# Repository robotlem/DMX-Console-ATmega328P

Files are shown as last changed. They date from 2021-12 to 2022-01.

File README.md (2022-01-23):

# DMX-Console-ATmega328P

A cheap and basic DMX console based on an ATmega328P

## About the Project

This DMX console is build for easy tasks like controlling a few spots, running a chaser for a light strip in the background or just testing DMX controlled lamps.
It is easy to use and build.

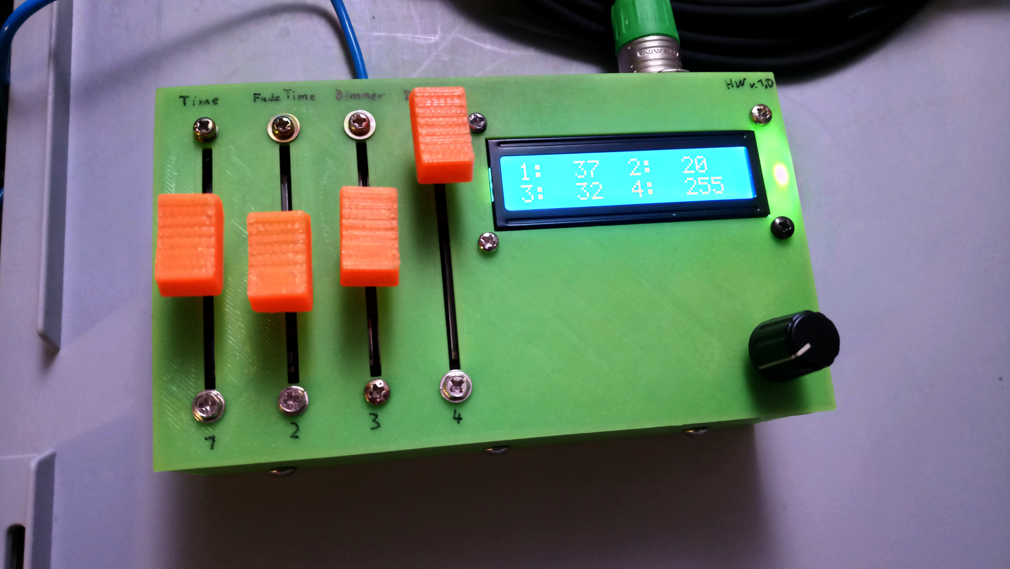
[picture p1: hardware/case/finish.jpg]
finish DMX-Controller


### Features

* Manual control of 72 DMX channels
* 3 Chaser banks which each contains 20 scenes, that stores the first 8 DMX channels
* Alltogether 60 Scenes store- and recallable
* Chaser parameter with faders settable (scenetime, fadetime, dimmer, direction)
* Startmode settable (manual, scene recall, chaser)
* relativly cheap (under 30€)

### Libaries used

* Arduino
* EEPROM
* marcoschwartz/LiquidCrystal_I2C@^1.1.4
* mathertel/RotaryEncoder@^1.5.2
* paulstoffregen/DmxSimple@^3.1 (modified, details in software folder)

### License

This project stands under the GNU GPLv3 License - see the LICENSE.md file for details.

## How2 Build

The circuit and BOM is in the hardware folder.
Build the "mainboard" on a perfboard and connect the faders, the LCD, ... with it.
You can also add a voltage regulator to use it with higher voltage.

To flash the software, connect the console (through a programmer) to your computer (if you are using a new ATmega328P you should burn a fitting bootloader first to set the fuses right).
Upload the prepare program (which updates the EEPROM to right start values).
Upload the main program.

Now you can build the components in a fitting case (you find an example in the hardware folder).

## Bugs

There could be some bugs left...
  - the fade time on the LCD is wrong

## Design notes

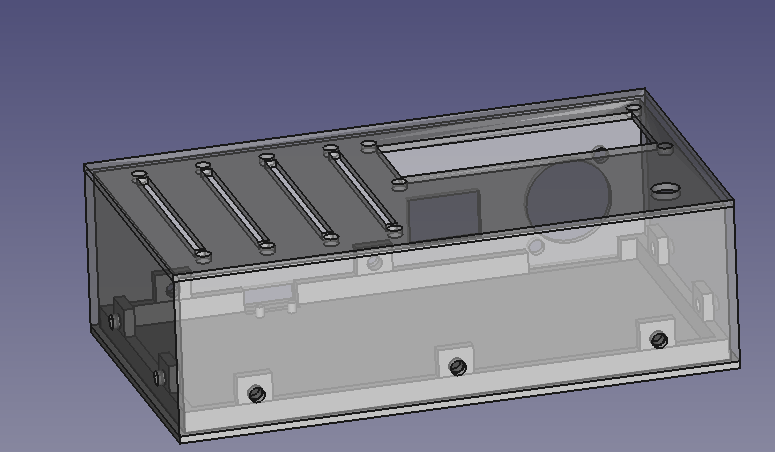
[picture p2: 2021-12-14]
hardware/case/Screenshot_20211214_175523.png

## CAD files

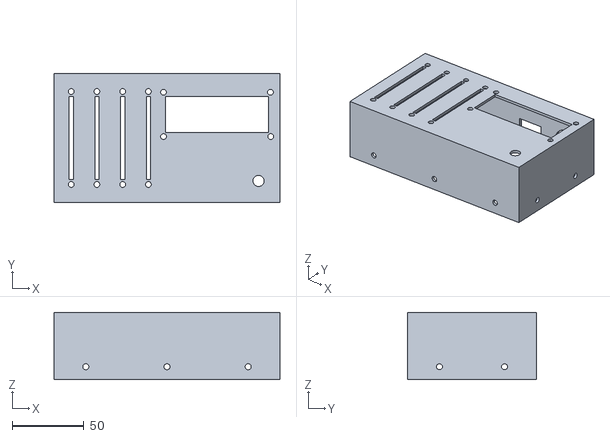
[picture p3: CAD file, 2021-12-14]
hardware/case/Gehäuse V1-OberteilPocket009.stl
158.0 x 90.0 x 47.0

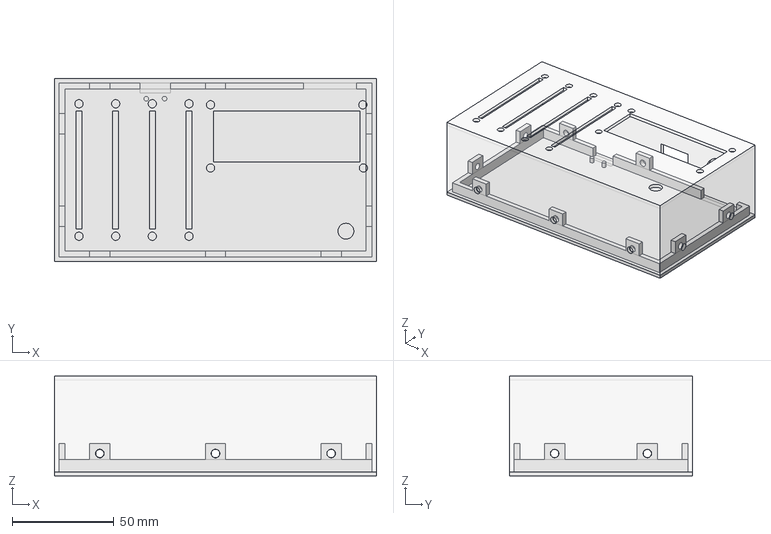
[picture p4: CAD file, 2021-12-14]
hardware/case/Gehäuse V1.FCStd
158.0 x 90.0 x 49.0 mm
Oberteil
Unterteil

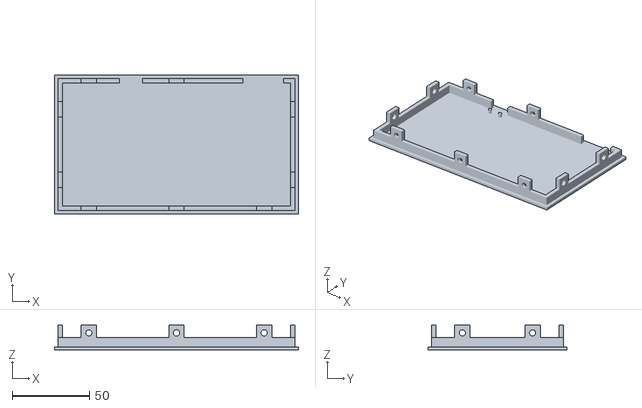
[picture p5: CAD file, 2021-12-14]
hardware/case/Gehäuse V1-UnterteilPad010.stl
158.0 x 90.0 x 16.0

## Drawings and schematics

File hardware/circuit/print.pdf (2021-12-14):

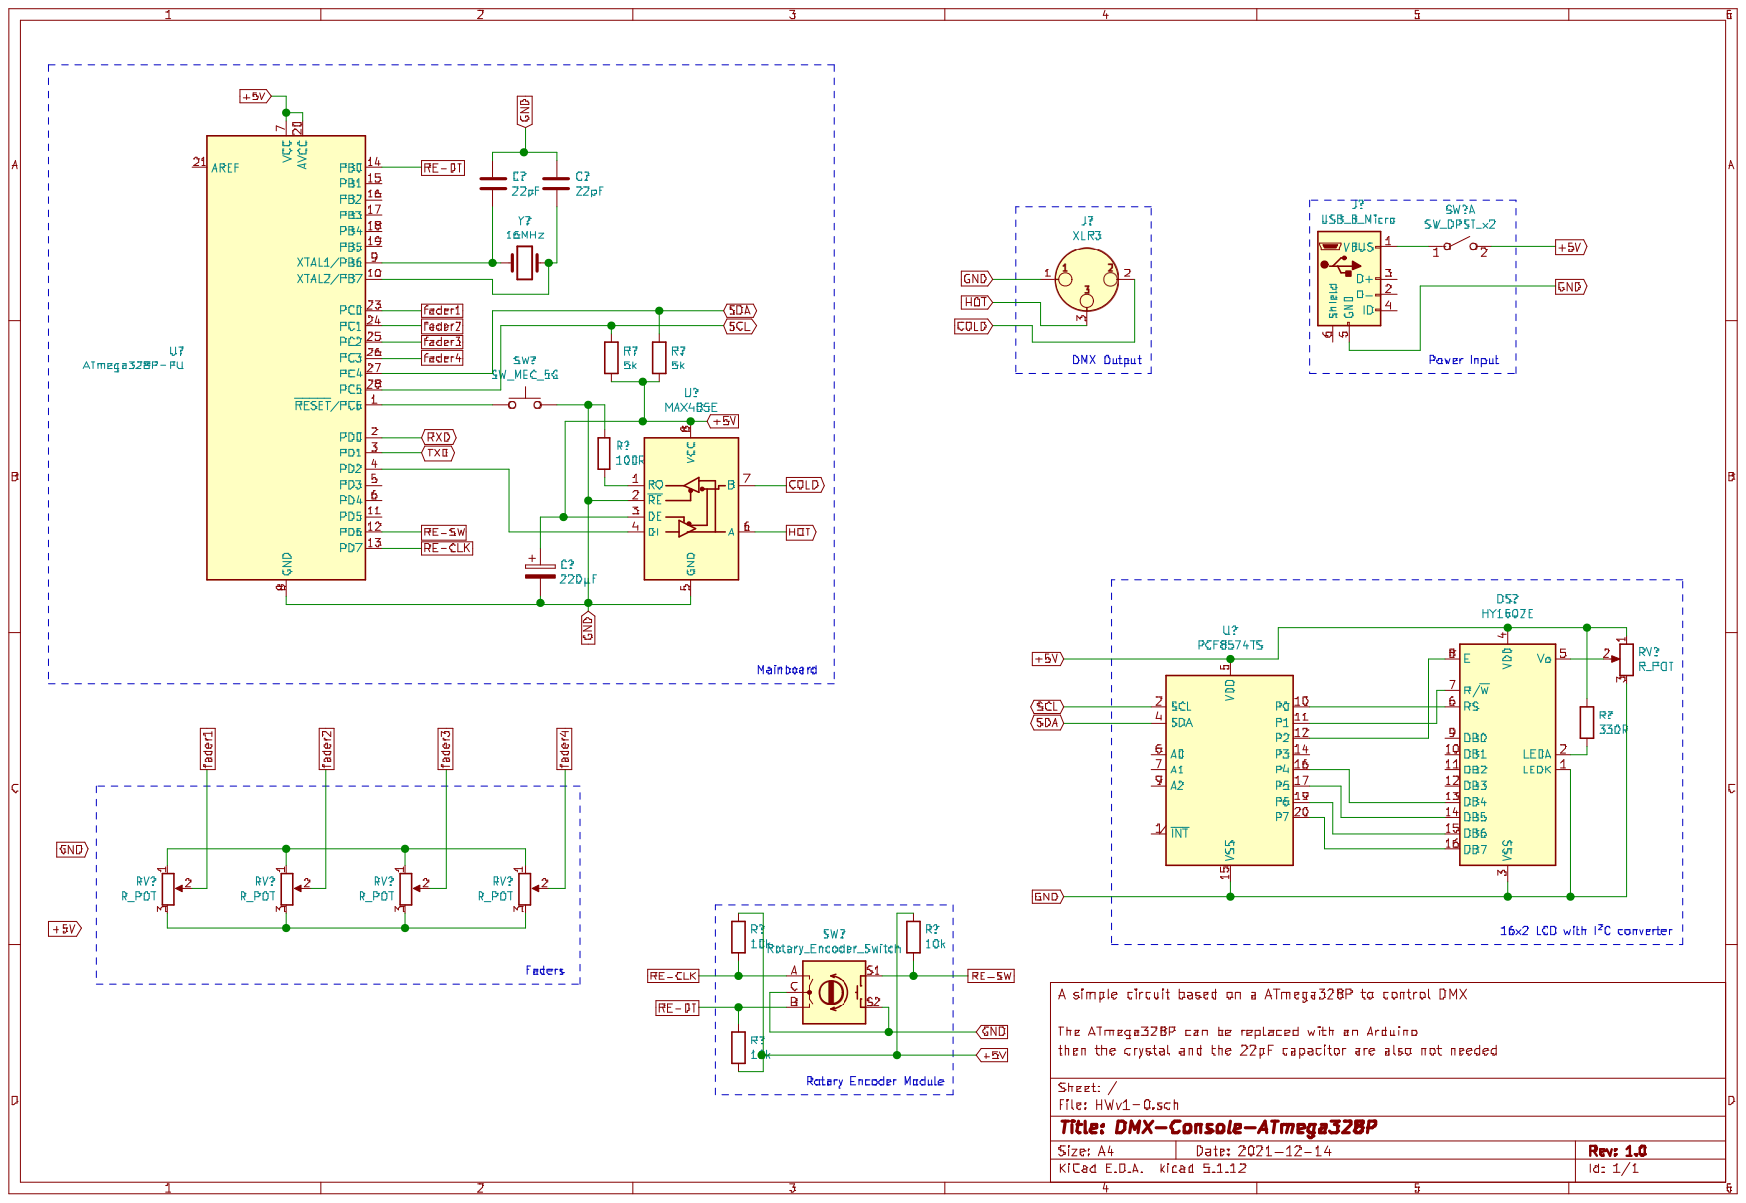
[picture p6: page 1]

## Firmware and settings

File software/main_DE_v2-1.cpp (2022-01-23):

/*
    DMX Controller v2.1
    Copyright (C) 2022 S.Pauthner

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
    You should have received a copy of the GNU General Public License
    along with this program.  If not, see <https://www.gnu.org/licenses/>.
*/

#include <Arduino.h>
#include <LiquidCrystal_I2C.h>
#include <RotaryEncoder.h>
#include <DmxSimple.h>
#include <EEPROM.h>

/* ---  DMX-Controller V2.1 ---
  Programmcode zur Steuerung von DMX Geräten
  für Hardware Version: 1.0
  Software Version:     2.1 beta
  Autor:                S. Pauthner
  Änderungsdatum:       23.01.2022

  Bibliotheken:         LiquidCrystal_I2C, RotaryEncoder, DmxSimple (! Enthält eigene Modifizierungen), EEPROM, Arduino
  Lizenz:               GNU GPLv3

  Features:           - manuelle Steuerung von 72 DMX Kanälen
                      - 3 Chaser mit 20 Scenen der ersten 8 Kanäle
                      - Anpasung der Chaserparameter mit Fadern
                      - einstellbarer Startmodus
                      - insgesamt 60 speicher und abrufbare Scenen á 8 Kanäle in 3 Chasern

  Bugfixes:
                      - FadeTime Anzeige korrigiert
                      - Chaserstart optimiert
                      - LCD update Zeit optimiert

  Default-verkabelung:
    PC6/Reset   --> Taster zu GND
    PD0/RXD     --> Serial Interface
    PD1/TXD     --> Serial Interface
    PD2/D2      --> MAX 485 CPA
    PD3/D3      --> N.C.
    PD4/D4      --> N.C.
    PB6/XTAL1   --> Oszillator 16MHz
    PB7/XTAL2   --> Oszillator 16MHz
    PD5/D5      --> N.C.
    PD6/D6      --> Drehencoder SW
    PD7/D7      --> Drehencoder CLK
    PB0/D8      --> Drehencoder DT

    PB1/D9      --> N.C.
    PB2/D10     --> N.C.
    PB3/D11     --> N.C.
    PB4/D12     --> N.C.
    PB5/D13     --> LED
    PC0/A0      --> Fader 1
    PC1/A1      --> Fader 2
    PC2/A2      --> Fader 3
    PC3/A3      --> Fader 4
    PC4/SCL     --> I²C Display SDA
    PC5/SDA     --> I²C Display SCL
*/

#define PIN_IN1 7   // Drehencoder CLK
#define PIN_IN2 8   // Drehencoder DT
#define PIN_BTN 6   // Drehencoder SW

#define Fader1  0   // Faderbelegung #1
#define Fader2  1   // Faderbelegung #2
#define Fader3  2   // Faderbelegung #3
#define Fader4  3   // Faderbelegung #4
static uint8_t faderInput[4] = {Fader1, Fader2, Fader3, Fader4};

LiquidCrystal_I2C lcd(0x27,16,2);                                               // Objekt lcd erzeugen (I²C Adresse, Spalten, Zeilen)
RotaryEncoder encoder(PIN_IN1, PIN_IN2, RotaryEncoder::LatchMode::TWO03);       // Objekt encoder erzeugen

/* DMX Output */
// DMX Output abrufen mit   DmxSimple.getValue(Channel);    --> Bibliotheksveränderung siehe Anhang "/doc/Recources/README"

/* Chaser Parameter */
unsigned short sceneSpeed = 0;    // die Zeit pro Scene in 100 ms
unsigned short fadeTime = 0;      // die Fadezeit bis zum letztendlichen Wert in 100 ms
unsigned short masterDimmer = 0;  // der Masterdimmer bei Chaseraktivitäten in Prozent (Multiplikator)
unsigned short richtung = 0;      // die Richtung, in der Scenen im Chaser abgerufen werden (Aufsteigend, Absteigend, Hin und Her, Zufall)
static double aktScene[8];        // die aktuelle Chaserscene
static double altScene[8];        // die vorherige Chaserscene
unsigned long timeScene = millis(); // Zeitvariable zur Scenenverwaltung
unsigned long timeFade = millis();// Zeitvariable zur Fadesteuerung
bool nurNull = false;             // Variable zur Überprüfung der Scenenwerte
bool scenedir = true;             // Variable für Hin Her
short fadePosition = 0;           // Variable zum Faden im Chaser (in 255 Schritten)
short lastChaserNr = 0;           // Variable, die die Letzte Scenennummer trägt --> hin her funktion

/* Programmablauf/-steuerung */
static unsigned short lcdUpdateTime = 200; // Anzahl der Millisekunden, bis das LCD geupdatet wird
static uint8_t status[4];         // aktuelle Aufgabe
static uint8_t statusebene = 0;   // Statusebene: 0 = Menu, 1 = Modusauswahl, 2 = Chaserauswahl, 3 = Scenenauswahl
static bool action = false;       // Select Button
static bool printRefresh = true;  // Variable, um das Lcd neu zu Zeichnen
static unsigned long time;        // Variable, die mit millis() gleichgesetzt wird, um ein zu häufiges Updaten des LCDs zu verhindern
static short fader[4];          // Fader Array --> ADC Wert durch 4
static bool faderChange[4] = {true, true, true, true};   // Variable, die bei Änderung der Fader auf true gesetzt wird


// Funktion, um den Drehencoder abzufragen
void trackRE(uint8_t position, uint8_t untergrenze, uint8_t obergrenze, uint8_t modifikator){
  /*
    byte position     : Welcher Index des Arrays/Pointers status/statusPointer modifiziert werden soll
    byte untergrenze  : Wo die Untergrenze der möglichen Werte liegt (Werte zwischen 0 und 255)
    byte obergrenze   : Wo die obergrenze der möglichen Werte liegt (Werte zwischen 0 und 255)
    byte modifikator  : Um wie viel der Wert erhöht bzw. verringert werden soll
  */
  static int pos = 0;
  encoder.tick();
  int newPos = encoder.getPosition();
  if (pos != newPos) {         // RE Aktionen
    // RE nach Links  -  Verringern
    if (pos > newPos+1){       // newPos + 1 um eine grobere erfassung zu bekommen
      if (status[position] <= untergrenze){
        status[position] = obergrenze;
      }
      else{
        status[position] = status[position] - modifikator;
      }
      printRefresh = true;
      pos = newPos;
    }
    // RE nach Rechts  -  Erhöhen
    else if (pos < newPos-1){  // newPos - 1 um eine grobere erfassung zu bekommen
      if (status[position] >= obergrenze){
        status[position] = untergrenze;
      }
      else{
        status[position] = status[position] + modifikator;
      }
      printRefresh = true;
      pos = newPos;
    }

  }
}

// Funktion um einen losgelassenen Selectbutton in eine Variable zu speichern
void buttonPress(){
  /*
    Push RE auslesen
    bei loslassen wird *actionPointer auf true gesetzt
      --> manuelles resetten

    faderChange auf True setzen um werte neu zu laden
  */
  static bool btnPres = false; // Variable zum auslesen des Selectbuttons
  if (digitalRead(PIN_BTN) == false){
    btnPres = true;
  }
  if (digitalRead(PIN_BTN) == true && btnPres == true){
    btnPres = false;
    action = true;
    printRefresh = true;
    for (uint8_t i = 0; i < 4; i++) {
      faderChange[i] = true;
    }
  }

}

// setup Funktion
void setup(){
  lcd.init();                      // LCD initialisieren
  lcd.backlight();
  lcd.begin(16,2);
  lcd.setCursor(1,0);
  lcd.print("DMX-Controller");
  lcd.setCursor(6,1);
  lcd.print("v2.1");

  pinMode(PIN_BTN, INPUT);        // Select Button als Input konfigurieren

  DmxSimple.maxChannel(72);       // DMX universum auf 72 limitieren
  DmxSimple.usePin(2);            // DMX Output Pin: 2
  for (uint8_t i = 1; i <= 72; i++) {
    DmxSimple.write(i, 0);
  }

  for (uint8_t i = 0; i < 4; i++) {    // Anfangsmodus laden
    status[i] = EEPROM.read(600 + i);
  }
  statusebene = EEPROM.read(610);     // Anfangsebene laden

  if (status[0] == 3 || status[0] == 4) {               // Wenn Scene oder Chaser als start, einmal die Szenenaktivität ausführen
    action = true;
  }
  if (status[0] == 4){                                  // bei Chaserstart Scene 1 laden
    for (uint8_t i = 0; i < 8; i++) {
      aktScene[i] = EEPROM.read((status[1]*200 + status[2]*8 + i));
      if (aktScene[i] != 0) {
        nurNull = false;
      }
    }
  }



  delay(700);

}

// loop Funktion

void loop(){

  for (uint8_t i = 0; i < 4; i++) {   // Fader updaten

    if (analogRead(faderInput[i])/4 != fader[i]) {
      fader[i] = analogRead(faderInput[i])/4;
      faderChange[i] = true;
    }

  }

  switch (statusebene) {        // Aktivität nach Statusebene
    case 0: // Menuebene
      trackRE(0, 0, 5, 1);      // Rotary Encoder aktualisieren
      break;
    case 1: // Modusebene/Chaserauswahl
      if (status[0] >= 1 && status[0] <= 4){  // Scene hinzufügen, löschen, abrufen; Chaser Abrufen
        trackRE(1, 0, 3, 1);
      }
      else if (status[0] == 0) {  // Manuell
        trackRE(3, 0, 68, 4);
        for (uint8_t i = 0; i < 4; i++) {
          if (faderChange[i] == true) {
            DmxSimple.write(status[3] + 1 + i, fader[i]);
            faderChange[i] = false;
            printRefresh = true;
          }
        }
      }
      else{ // Einstellungen
          trackRE(1, 0, 3, 1);
      }
      break;

    case 2:
      if (status[0] == 5){  // Einstellungen Chaserauswahl
        trackRE(2, 0, 3, 1);
      }
      else if (status[0] == 4){ // Chaserausführung
        trackRE(2, 0, 19, 1);               // Scrollfunktion durch die Scenen

        for (uint8_t i = 0; i < 4; i++) {   // Manipulationsvariablen anpassen
          if (faderChange[i] == true) {
            switch (i) {
              case 0: // sceneSpeed
                sceneSpeed = (fader[i]*100)/85;
                break;
              case 1: // fadeTime
                fadeTime = (fader[i]*100)/255;
                break;
              case 2: // Dimmer
                masterDimmer = (fader[i]*100)/255;
                for (short i = 0; i < 8; i++) {
                  DmxSimple.write(i + 1 , ((altScene[i] + (((aktScene[i] - altScene[i])/255)*fadePosition))*masterDimmer) / 100 );
                }
                break;
              case 3: // Richtung
                if (fader[i] <= 4){
                  richtung = 0;   // Aufsteigend
                }
                else if (fader[i] <= 38){
                  richtung = 1;   // Absteigend
                }
                else if (fader[i] <= 175){
                  richtung = 2;   // Hin und Her
                }
                else{
                  richtung = 3;   // Zufällig
                }
            }
            faderChange[i] = false;
            printRefresh = true;
          }
        }

        if (millis() - timeScene >= sceneSpeed * 100) { // Eine Scene weiter/ ein Step
          lastChaserNr = status[2];
          for (uint8_t i = 0; i < 8; i++) { // aktuelle Scene in alteScene Speichern
            altScene[i] = aktScene[i];
          }
          nurNull = true;
          int n = 0;
          while(nurNull == true && n < 40){           // aktuelle Scene aus EEPROM lesen und auf NUR NULL prüfen
            n++;
            switch (richtung) {     // Neue Scenennummer erstellen
              case 0: // aufsteigend
                status[2] = status[2] + 1;
                if (status[2] >= 20){
                  status[2] = 0;
                }
                break;
              case 1: // Absteigend
                if (status[2] <= 0) {
                  status[2] = 19;
                }
                else{
                status[2] = status[2] - 1;
                }
                break;
              case 2: // Hin und Her
                if (scenedir == true){    // Aufsteigender Part
                  status[2] = status[2] + 1;
                  if (status[2] >= 19) {
                    scenedir = false;
                  }
                  if (status[2] == lastChaserNr && status[2] <=18) {
                    status[2] = status[2] + 1;
                  }
                }
                else{                     // Sinkender Part
                  status[2] = status[2] - 1;
                  if (status[2] <= 0){
                    scenedir = true;
                  }
                  if (status[2] == lastChaserNr && status[2] >= 1) {
                    status[2] = status[2] - 1;
                  }
                }
                break;
              case 3: // Zufall
                status[2] = random(0, 19);
                break;
              }
              for (uint8_t i = 0; i < 8; i++) {
                aktScene[i] = EEPROM.read((status[1]*200 + status[2]*8 + i));
                if (aktScene[i] != 0) {
                  nurNull = false;
                }
              }
              fadePosition = 0;

          }
          n = 0;
          timeScene = millis();
          printRefresh = true;
        }

        if ((millis() - timeFade >= fadeTime && fadePosition < 256) && fadeTime > 0){ // Faden ermöglichen
          for (short i = 0; i < 8; i++) {
            DmxSimple.write(i + 1 , ((altScene[i] + (((aktScene[i] - altScene[i])/255)*fadePosition))*masterDimmer) / 100 );
          }
          fadePosition = fadePosition + 1;
          timeFade = millis();
        }
        else if (fadeTime <=0 ) {
          for (short i = 0; i < 8; i++) {
            DmxSimple.write(i + 1 , ((aktScene[i])*masterDimmer) / 100 );
          }
          fadePosition = 256;
        }


      }
      else{
        trackRE(2, 0, 20, 1);
      }
      break;
    case 3:
      trackRE(3, 0, 20, 1);
      break;
  }

  buttonPress();            // Select Button aktualisieren

  if (action == true){      // Aktion beim drücken des Select Buttons

    // Zurück (Szene hinzufügen, löschen, abrufen; Chaser Abrufen)
    if ( ((status[1] == 3 && statusebene == 1) || (status[2] == 20 && statusebene == 2)) && (status[0] >= 1 && status[0] <= 4) ){
      if (statusebene <= 0){
        statusebene = 0;
      }
      else{
        statusebene = statusebene - 1;
      }
    }
    // auswählen (Szene hinzufügen, löschen, abrufen; Chaser Abrufen)
    else if (status[0] >= 1 && status[0] <= 4) {
      // Chaserabruf Zurück
      if (status[0] == 4 && statusebene >= 2){
        statusebene = statusebene - 2;
      }

      if (statusebene >= 2){  // Aktionsebene
        switch (status [0]){
          case 1: // Scene hinzufügen
            for (uint8_t i = 0; i < 8; i++) {
              EEPROM.update((status[1]*200) + status[2]*8 + i, DmxSimple.getValue(i + 1));  // Erste 8 DMX Werte in EEPROM speichern
            }
            status[0] = 0;  // Manuell
            statusebene = 0;// Manuell auswahl auf false --> wird im Abschnitt unten umgetriggerd
            break;
          case 2: // Scene löschen
            for (uint8_t i = 0; i < 8; i++) {
              EEPROM.update((status[1]*200) + status[2]*8 + i, 0);  // Erste 8 DMX Werte in EEPROM auf 0 setzen --> nur Null scenen werden ignoriert
            }
            break;
          case 3: // Scene Abrufen
            for (uint8_t i = 0; i < 8; i++) {
              DmxSimple.write(1 + i, EEPROM.read((status[1]*200) + status[2]*8 + i));  // 8 DMX Werte aus EEPROM lesen und ausgeben
            }
            break;
        }
      }
      else {
        statusebene = statusebene + 1;
      }
    }

    // Manuell
    if (status[0] == 0) {
      if (statusebene == 0){
        statusebene = 1;
      }
      else{
        statusebene = 0;
      }
    }
    // Einstellungen
    if (status[0] == 5){
      switch (statusebene) {
        case 0: // Auswahl des Startmodus Menueintrag
          statusebene = statusebene + 1;
          status[1] = 0;
          status[2] = 0;
          status[3] = 0;
          break;
        case 1: // Auswahl zwischen Manuell, Scene, Chaser und Zurück
          if (status[1] == 3){ // Zurück zum Hauptmenu
            statusebene = 0;
          }
          else if (status[1] == 0){ // Manuell ausgewählt
            for (uint8_t i = 0; i < 4; i++) {
              EEPROM.update(600 + i, 0);  // Modus speichern
            }
            EEPROM.update(610, 1);  // Statusebene speichern
            statusebene = 0;
          }
          else{
            statusebene = statusebene + 1;
          }
          break;
        case 2: // Auswahl des Chasers
          if (status[2] == 3) {     // Zurück
            statusebene = statusebene - 1;
          }
          else if (status[1] == 2) {     // Chaserauswahl
                                         // Chaser als modus speichern
            uint8_t startwerte[4] = {4, status[2], 0, 0};
            for (size_t i = 0; i < 4; i++) {
              EEPROM.update(600 + i, startwerte[i]);
            }
            EEPROM.update(610, 1);
            statusebene = 0;
          }
          else{   // Weiterleitung zur Scenenauswahl
            statusebene = statusebene + 1;
            status[3] = 0;
          }
          break;
        case 3: // Auswahl der Scene
          if (status[3] == 20){ // Zurück
            statusebene = statusebene - 1;
          }
          else{
            uint8_t werteStart[4] = {3, status[2], status[3], 0};
            for (size_t i = 0; i < 4; i++) {
              EEPROM.update(600 + i, werteStart[i]);
            }
            EEPROM.update(610, 2);
            statusebene = 0;
          }
          break;

      }

    }



    action = false;
  }

  if (printRefresh == true && millis()-time > lcdUpdateTime) {   // LCD updaten
    lcd.clear();
    static String menueintraege[] = {"Manuell", "Scene hinzuf\365gen", "Scene l\357schen", "Scene abrufen", "Chaser abrufen", "Einstellungen"};
    static String chaserAddIcon[] = {"+", "-", "#", "~"};
    static String chaserauswahl[] = {"Chaser 1", "Chaser 2", "Chaser 3", "Zur\365ck"};
    static String einstellungen[] = {menueintraege[0], menueintraege[3], menueintraege[4], chaserauswahl[3]};

    switch (statusebene) {
      case 0: //Menuebene
        lcd.print("Hauptmenu");
        lcd.setCursor(0, 1);
        lcd.print(menueintraege[status[0]]);
        break;
      case 1: // Modusebene/Chaserauswahl
        if (status[0] >= 1 && status[0] <= 4){     // Chaser Auswahl
          lcd.print(chaserAddIcon[status[0]-1]);
          lcd.print(" Chaser Auswahl");
          lcd.setCursor(0, 1);
          lcd.print(chaserauswahl[status[1]]);
        }
        else if (status[0] == 0){  // Manuell
          lcd.print(status[3]+1);
          lcd.print(": ");
          lcd.setCursor(4, 0);
          lcd.print(DmxSimple.getValue(status[3]+1));
          lcd.setCursor(8, 0);
          lcd.print(status[3]+2);
          lcd.print(": ");
          lcd.setCursor(12, 0);
          lcd.print(DmxSimple.getValue(status[3]+2));
          lcd.setCursor(0, 1);
          lcd.print(status[3]+3);
          lcd.print(": ");
          lcd.setCursor(4, 1);
          lcd.print(DmxSimple.getValue(status[3]+3));
          lcd.setCursor(8, 1);
          lcd.print(status[3]+4);
          lcd.print(": ");
          lcd.setCursor(12, 1);
          lcd.print(DmxSimple.getValue(status[3]+4));
        }
        else {                      // Einstellungen
          lcd.print("Startmodus");
          lcd.setCursor(0, 1);
          lcd.print(einstellungen[status[1]]);
        }
        break;
      case 2: // Scenenauswahl
        if (status[0] >= 1 && status[0] <= 3){     // Scenen Auswahl
          lcd.print(chaserAddIcon[status[0]-1]);
          lcd.print(" Scene Auswahl");
          lcd.setCursor(0, 1);
          if (status[2] != 20){
            lcd.print("Ch");
            lcd.print(status[1]+1);
            lcd.print(" Scene: ");
            lcd.print(status[2]+1);
          }
          else{
            lcd.print(chaserauswahl[3]);
          }
        }
        if (status[0] == 4){      // Chasermodus
          static String dirArray[4] = {">>>", "<<<", "> <", " Z "};
          lcd.print("T-s T-f Dim ");
          lcd.print(status[1]+1);
          lcd.print("#");
          lcd.print(status[2]+1);
          lcd.setCursor(0, 1);
          lcd.print(sceneSpeed/10);
          lcd.print("s");
          lcd.setCursor(4, 1);
          lcd.print(fadeTime/2);
          lcd.print("s");
          lcd.setCursor(8, 1);
          lcd.print(masterDimmer);
          lcd.print("%");
          lcd.setCursor(13, 1);
          lcd.print(dirArray[richtung]);
        }
        if (status[0] == 5){      // Einstellungen Chaser auswahl
          lcd.print(einstellungen[status[1]]);
          lcd.setCursor(0, 1);
          lcd.print(chaserauswahl[status[2]]);
        }
        break;
      case 3:
        if (status[0] == 5){
          lcd.print("Scene Auswahl");
          lcd.setCursor(0, 1);
          if (status[3] != 20){
            lcd.print("Ch");
            lcd.print(status[2]+1);
            lcd.print(" Scene: ");
            lcd.print(status[3]+1);
          }
          else{
            lcd.print(chaserauswahl[3]);
          }
        }

    }

    printRefresh = false;
    time = millis();
  }


}

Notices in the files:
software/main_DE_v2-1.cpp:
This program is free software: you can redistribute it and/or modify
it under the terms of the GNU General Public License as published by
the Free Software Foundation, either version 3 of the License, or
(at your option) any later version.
